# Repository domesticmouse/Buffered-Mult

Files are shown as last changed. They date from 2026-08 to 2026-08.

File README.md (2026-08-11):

# Buffered-Mult

A 3-channel active buffered mult (multiple) circuit designed for Eurorack modular synthesizers. View this in [KiCanvas](https://kicanvas.org/?repo=https%3A%2F%2Fgithub.com%2Fdomesticmouse%2FBuffered-Mult).

## Purpose

In modular synthesis, a **multiple** is used to split a single signal (such as control voltage, gates/triggers, or audio) and route it to multiple destinations simultaneously.

While passive multiples simply wire jacks together in parallel, they cause **voltage droop** when splitting precise voltages like 1V/Octave pitch CV across multiple inputs due to impedance loading. This results in out-of-tune oscillators and pitch tracking errors.

This **buffered mult circuit** solves that problem by using active operational amplifiers configured as unity-gain buffers:

- **1:1 Voltage Precision:** Maintains accurate voltage levels (essential for 1V/Oct pitch CV) across all outputs without signal drop.
- **Impedance Isolation:** High input impedance presents virtually no load to the source signal, while low output impedance cleanly drives downstream module inputs.
- **Channel Isolation:** Prevents attached modules from loading or interfering with each other.

---

## Specifications

### Dimensions
- **Height:** 3U (Eurorack format)
- **Width:** 6HP
- **Faceplate:** Complete mechanical specifications and KiCad panel design are available in [`faceplate/README.md`](faceplate/README.md).

See Exploding Shed's [Eurorack Dimensions Guide](https://www.exploding-shed.com/synth-diy-guides/standards-of-eurorack/eurorack-dimensions/) for sizing a 6hp module.

### Inputs
- **3× 3.5 mm mono input jacks:**
  - Input 2 is normalled to Input 1.
  - Input 3 is normalled to Input 2.
- **Cascading Normalling Routing:**
  - **1 Input patched (Input 1):** Functions as a **1×9** mult (1 input split to 9 outputs).
  - **2 Inputs patched (Inputs 1 & 2):** Functions as **1×3** (Input 1) and **1×6** (Input 2) mults.
  - **3 Inputs patched (Inputs 1, 2 & 3):** Functions as **3 independent 1×3** mults.
- **100 kΩ pulldown resistors** (`R1`–`R3`) on inputs to prevent floating inputs when unpatched.
- **Input ESD & RF Filtering:** 1 kΩ series resistors (`R16`–`R18`) and 100 pF capacitors (`C9`–`C11`) provide high-frequency noise filtering and ESD protection.

### Outputs
- **9× 3.5 mm mono output jacks:** 3 dedicated buffered outputs for each of the 3 input channels.
- **1 kΩ Short-Circuit Protection:** Output series resistors (`R7`–`R15`) protect op-amps during cable insertion/patching shorts while maintaining stability under capacitive cable loads.
- **Bipolar LED Indication:** Opposing-polarity LED pairs (`D1`–`D6`) driven by dedicated active op-amp constant-current stages (`R4`–`R6`) indicate positive (+) and negative (-) voltage states without loading signal lines.

---

## Circuit & Physical Design

- **TL074 Quad Operational Amplifiers:** Configured as high-impedance unity-gain buffers (`U1`, `U2`, `U3`).
- **Active Visual Feedback:** 4th op-amp stage on each TL074 drives bipolar indicator LEDs in a constant-current feedback arrangement.
- **Power Connector:** Standard 2×5-pin IDC header (`J1`) for Eurorack ±12V power connection.
- **Power Filtering & Decoupling:** Bulk 10 µF electrolytic capacitors (`C7`, `C8`) on power entry rails plus 100 nF ceramic decoupling capacitors (`C1`–`C6`) per IC package.
- **Reverse Power Protection:** MBR0520 Schottky diodes (`D7`, `D8`) protect against reverse ribbon cable insertion.
- **Two-Sided Board Layout:** All SMT components on top layer (`F.Cu`); through-hole jacks and LEDs on bottom layer (`B.Cu`) for front panel mounting.

---

## Verification & Fabrication

- **KiCad Electrical Rules Check (ERC):** 0 Errors, 0 Warnings on main board schematic.
- **KiCad Design Rules Check (DRC):** 0 Track / Clearance Errors on main board and faceplate PCB.
- **JLCPCB Automated Assembly Ready:** Complete Gerber ZIP, SMT BOM (`BOM-Buffered-Mult.csv`), and Centroid CPL (`CPL-Buffered-Mult.csv`) generated in [`jlcpcb/production_files/`](jlcpcb/production_files/).
- **Faceplate Fabrication:** Complete KiCad project, panel Gerber files, and drill specs in [`faceplate/`](faceplate/).

## License

BufferedMult is open source and available under the [Apache License 2.0](LICENSE).

## Disclaimer

This is not an official Google product.

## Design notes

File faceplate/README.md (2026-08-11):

# Buffered Mult Faceplate

This directory contains the mechanical specifications and KiCad panel files for the [Buffered Mult control board](../Buffered-Mult.kicad_pro) faceplate.

---

## Technical Specifications

### Panel Outer Dimensions
- **Format:** 3U Eurorack (6 HP width)
- **Height:** 128.50 mm (±0.20 mm tolerance)
- **Width:** 30.00 mm (incorporates standard -0.48 mm clearance against nominal 30.48 mm to prevent rail binding)
- **Thickness:** 1.60 mm (standard PCB FR4) or 2.00 mm aluminum

---

## Mechanical Clearance & Drill Specifications

### 1. Mounting Screw Slots
To allow minor horizontal alignment adjustments when mounting modules:
- **Screw Size:** M3 (3.0 mm)
- **Slot Shape:** Horizontal oval slot
- **Slot Dimensions:** 6.00 mm (width) × 3.20 mm (height)
- **Hole Center Spacing (Vertical):** 122.50 mm (3.00 mm margin from top and bottom panel edges)
- **Hole Center Spacing (Horizontal):** 7.50 mm from left and right edges (22.50 mm offset center-to-center)

### 2. Component Hole Diameters & Tolerances

| Component | Nominal Size | Recommended Drill Dia. | Clearance Margin | Notes |
| :--- | :--- | :--- | :--- | :--- |
| **3.5mm Audio Jacks** | M6 Bushing (6.0 mm) | **6.10 mm – 6.20 mm** | +0.10 mm to +0.20 mm | Accommodates QingPu WQP-PJ398SM / Thonkiconn PJ301M threaded bushings and solder mask build-up. |
| **Indicator LEDs** | 3.0 mm THT LED | **3.20 mm** | +0.20 mm | Ensures smooth fit for 3mm flat-top LEDs or lightpipes without binding. |
| **Mounting Slots** | M3 Screws | **3.20 mm × 6.00 mm** | +0.20 mm | Standard Eurorack oval mounting slot. |

---

## Component Layout & Grid

The panel accommodates **3 identical channel groups** (Channel 1, Channel 2, Channel 3) vertically aligned.

### Per-Channel Grid Layout

| Position | Left Column | Right Column |
| :--- | :--- | :--- |
| **Top Row** | Negative LED Indicator (-) | Positive LED Indicator (+) | 
| **Middle Row** | Channel Input Jack | Output Jack 1 |
| **Bottom Row** | Output Jack 2 | Output Jack 3 |

### Faceplate Component Placements

Faceplate to Control Panel offset = (128.5 - 110)/2 = 9.25mm

Distance between channel groups, 29mm vertical separation.

Measurements from top left of control board.

#### Channel 1

- D1: Negative LED Indicator (-)
  - x: 5.77mm
  - y: 7mm
- D2: Positive LED Indicator (+)
  - x: 11.27mm
  - y: 7mm
- J2: Channel 1 Input Jack
  - x: 8.48mm
  - y: 15mm
- J5: Channel 1 Output Jack 1
  - x: 21.52mm
  - y: 15mm
- J6: Channel 1 Output Jack 2
  - x: 8.48mm
  - y: 25mm
- J7: Channel 1 Output Jack 3
  - x: 21.52mm
  - y: 25mm

#### Channel 2

- D3: Negative LED Indicator (-)
  - x: 5.77mm
  - y: 36mm
- D4: Positive LED Indicator (+)
  - x: 11.27mm
  - y: 36mm
- J3: Channel 2 Input Jack
  - x: 8.48mm
  - y: 44mm
- J8: Channel 2 Output Jack 1
  - x: 21.52mm
  - y: 44mm
- J9: Channel 2 Output Jack 2
  - x: 8.48mm
  - y: 54mm
- J10: Channel 2 Output Jack 3
  - x: 21.52mm
  - y: 54mm

#### Channel 3

- D5: Negative LED Indicator (-)
  - x: 5.77mm
  - y: 65mm
- D6: Positive LED Indicator (+)
  - x: 11.27mm
  - y: 65mm
- J4: Channel 3 Input Jack
  - x: 8.48mm
  - y: 73mm
- J11: Channel 3 Output Jack 1
  - x: 21.52mm
  - y: 73mm
- J12: Channel 3 Output Jack 2
  - x: 8.48mm
  - y: 83mm
- J13: Channel 3 Output Jack 3
  - x: 21.52mm
  - y: 83mm

---

## KiCad Faceplate Design & Fabrication Guidelines

When designing the KiCad PCB faceplate (`faceplate.kicad_pcb`):

1. **Board Outline (Edge.Cuts):** Draw a exact 30.00 mm × 128.50 mm rectangle on `Edge.Cuts` with 0.5 mm fillet radii at the 4 outer corners.
2. **Copper & Mask Clearance:**
   - Keep copper traces and copper fills at least **0.50 mm away** from all board edges.
   - Add exposed unmasked copper rings connected to GND around mounting slots on front/back for ESD chassis grounding.
3. **Silkscreen Graphics:**
   - Use high-contrast silkscreen text (`F.Silkscreen` / `B.Silkscreen`).
   - Clearly label Channels (`CH 1`, `CH 2`, `CH 3`), Inputs (`IN`), Outputs (`1`, `2`, `3`), and LED polarities (`+`, `-`).
4. **Recommended PCB Fabrication Specs:**
   - **Material:** FR4, 1.6 mm thickness
   - **Solder Mask:** Black (Matte Black or Glossy Black)
   - **Silkscreen:** White
   - **Surface Finish:** HASL Lead-Free or ENIG (Electroless Nickel Immersion Gold)

---

## Reference Standards
* Exploding Shed [Eurorack Dimensions Guide](https://www.exploding-shed.com/synth-diy-guides/standards-of-eurorack/eurorack-dimensions/)
* Doepfer [Eurorack Mechanical Specifications](https://doepfer.de/a100_man/a100m_e.htm)

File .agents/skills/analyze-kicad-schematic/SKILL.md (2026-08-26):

---
name: analyze-kicad-schematic
description: >-
  Analyzes KiCad schematic files (.kicad_sch) and generates structured markdown
  reports or targeted query results (BOM, ERC, power rails, signal netlists,
  circuit topologies, unconnected pins). Use this skill when reviewing, auditing,
  or troubleshooting KiCad schematic designs.
---

# KiCad Schematic Analyzer

This skill provides automated analysis of KiCad 7/8/9/10+ schematic (`.kicad_sch`) files using `kicad-cli`. It supports **modular CLI subcommands** so you can query specific aspects of a schematic without polluting the context with monolithic reports, as well as generating full comprehensive Markdown reports.

## Prerequisites

- **uv** (preferred runtime) or **Python 3.6+**
- **KiCad CLI (`kicad-cli`)**: Auto-detected from system `PATH` or standard installation locations:
  - macOS: `/Applications/KiCad/KiCad.app/Contents/MacOS/kicad-cli`, `/Applications/KiCad <version>/...`, Homebrew (`/opt/homebrew/bin/kicad-cli`).
  - Linux: `/usr/bin/kicad-cli`, `/usr/local/bin/kicad-cli`, Snap, Flatpak.
  - Windows: `C:\Program Files\KiCad\<version>\bin\kicad-cli.exe`.

## Tool Script

The analysis script is located at:
- [`scripts/analyze_schematic.py`](./scripts/analyze_schematic.py)

---

## Discovering Commands & Options (`--help`)

Always check `--help` using `uv run --isolated` to inspect available query subcommands or specific subcommand flags:

```bash
# View top-level help and list of subcommands
uv run --isolated .agents/skills/analyze-kicad-schematic/scripts/analyze_schematic.py --help

# View help and filtering options for a specific subcommand
uv run --isolated .agents/skills/analyze-kicad-schematic/scripts/analyze_schematic.py nets --help
uv run --isolated .agents/skills/analyze-kicad-schematic/scripts/analyze_schematic.py bom --help
```

*(Fallback without uv: `python3 .agents/skills/analyze-kicad-schematic/scripts/analyze_schematic.py --help`)*

---

## Targeted Query Subcommands

Instead of running a monolithic report, prefer running the specific subcommand relevant to the question being asked:

| Subcommand | Description | When to use |
| :--- | :--- | :--- |
| `summary` | Design overview, KiCad version, sheet hierarchy, total components/nets | Initial inspection or high-level sanity check |
| `erc` | Runs ERC check (`kicad-cli sch erc`) and reports true electrical errors/warnings | Checking electrical validity, unrouted nets, or conflicts |
| `bom` | Consolidated Bill of Materials table grouped by value, footprint, LCSC/MPN | Part counting, component lookup, sourcing reviews |
| `topologies` (or `circuits`) | Detects RC filters (with $f_c$), op-amp voltage followers, LED feedback drivers | Circuit function understanding, analog verification |
| `power` | Power rails audit (`+12V`, `-12V`, `GND`, etc.) and all connected pins | Power distribution inspection, ground connection audits |
| `nets` | Signal netlist connections with optional `--net` or `--ref` filters | Tracing specific signals or inspecting pins of a component |
| `unconnected` | Unconnected physical pins and explicit no-connect flags | Finding missed connections or unrouted pins |
| `report` (or `all`) | Full comprehensive report combining all sections | Generating a complete archival design review document |

---

## Usage Examples

### 1. Inspect Bill of Materials (BOM)
```bash
uv run --isolated .agents/skills/analyze-kicad-schematic/scripts/analyze_schematic.py bom path/to/design.kicad_sch
```

### 2. Run Electrical Rules Check (ERC)
```bash
uv run --isolated .agents/skills/analyze-kicad-schematic/scripts/analyze_schematic.py erc path/to/design.kicad_sch
```

### 3. Trace a Specific Net or Component Pins
```bash
# Filter signal nets connected to component U1
uv run --isolated .agents/skills/analyze-kicad-schematic/scripts/analyze_schematic.py nets path/to/design.kicad_sch --ref U1

# Filter by net name (e.g. INPUT1)
uv run --isolated .agents/skills/analyze-kicad-schematic/scripts/analyze_schematic.py nets path/to/design.kicad_sch --net INPUT1
```

### 4. Audit Power Rails & Decoupling
```bash
uv run --isolated .agents/skills/analyze-kicad-schematic/scripts/analyze_schematic.py power path/to/design.kicad_sch
```

### 5. Check Unconnected / No-Connect Pins
```bash
uv run --isolated .agents/skills/analyze-kicad-schematic/scripts/analyze_schematic.py unconnected path/to/design.kicad_sch
```

### 6. Detect Circuit Topologies & Filter Cutoffs
```bash
uv run --isolated .agents/skills/analyze-kicad-schematic/scripts/analyze_schematic.py topologies path/to/design.kicad_sch
```

### 7. Generate Full Report to a File
```bash
uv run --isolated .agents/skills/analyze-kicad-schematic/scripts/analyze_schematic.py report path/to/design.kicad_sch -o path/to/report.md
```

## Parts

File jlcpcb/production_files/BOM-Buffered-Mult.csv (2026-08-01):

Comment | Designator | Footprint | LCSC | Quantity
100K | R1,R2,R3 | R_0603_1608Metric_Pad0.98x0.95mm_HandSolder | C25803 | 3
100nF | C1,C2,C3,C4,C5,C6 | C_0603_1608Metric_Pad1.08x0.95mm_HandSolder | C14663 | 6
100pF | C10,C11,C9 | C_0603_1608Metric_Pad1.08x0.95mm_HandSolder | C14858 | 3
10uF/25V | C7,C8 | CP_Elec_5x5.4 | C46550416 | 2
1k | R10,R11,R12,R13,R14,R15,R16,R17,R18,R4,R5,R6,R7,R8,R9 | R_0603_1608Metric_Pad0.98x0.95mm_HandSolder | C21190 | 15
D_Schottky | D7,D8 | D_SMA_Handsoldering | C2480 | 2
TL074 | U1,U2,U3 | SOIC-14_3.9x8.7mm_P1.27mm | C2878713 | 3
OUTPUT3-3 | J13 | Jack_3.5mm_QingPu_WQP-PJ398SM_Vertical_CircularHoles |  | 1
OUTPUT3-2 | J12 | Jack_3.5mm_QingPu_WQP-PJ398SM_Vertical_CircularHoles |  | 1
OUTPUT3-1 | J11 | Jack_3.5mm_QingPu_WQP-PJ398SM_Vertical_CircularHoles |  | 1
OUTPUT2-3 | J10 | Jack_3.5mm_QingPu_WQP-PJ398SM_Vertical_CircularHoles |  | 1
OUTPUT2-2 | J9 | Jack_3.5mm_QingPu_WQP-PJ398SM_Vertical_CircularHoles |  | 1
OUTPUT2-1 | J8 | Jack_3.5mm_QingPu_WQP-PJ398SM_Vertical_CircularHoles |  | 1
OUTPUT1-3 | J7 | Jack_3.5mm_QingPu_WQP-PJ398SM_Vertical_CircularHoles |  | 1
OUTPUT1-2 | J6 | Jack_3.5mm_QingPu_WQP-PJ398SM_Vertical_CircularHoles |  | 1
OUTPUT1-1 | J5 | Jack_3.5mm_QingPu_WQP-PJ398SM_Vertical_CircularHoles |  | 1
INPUT3 | J4 | Jack_3.5mm_QingPu_WQP-PJ398SM_Vertical_CircularHoles |  | 1
INPUT2 | J3 | Jack_3.5mm_QingPu_WQP-PJ398SM_Vertical_CircularHoles |  | 1
INPUT1 | J2 | Jack_3.5mm_QingPu_WQP-PJ398SM_Vertical_CircularHoles |  | 1
Eurorack PWR | J1 | IDC-Header_2x05_P2.54mm_Vertical |  | 1
LED | D6 | LED_D3.0mm_FlatTop |  | 1
LED | D5 | LED_D3.0mm_FlatTop |  | 1
LED | D4 | LED_D3.0mm_FlatTop |  | 1
LED | D3 | LED_D3.0mm_FlatTop |  | 1
LED | D2 | LED_D3.0mm_FlatTop |  | 1
LED | D1 | LED_D3.0mm_FlatTop |  | 1

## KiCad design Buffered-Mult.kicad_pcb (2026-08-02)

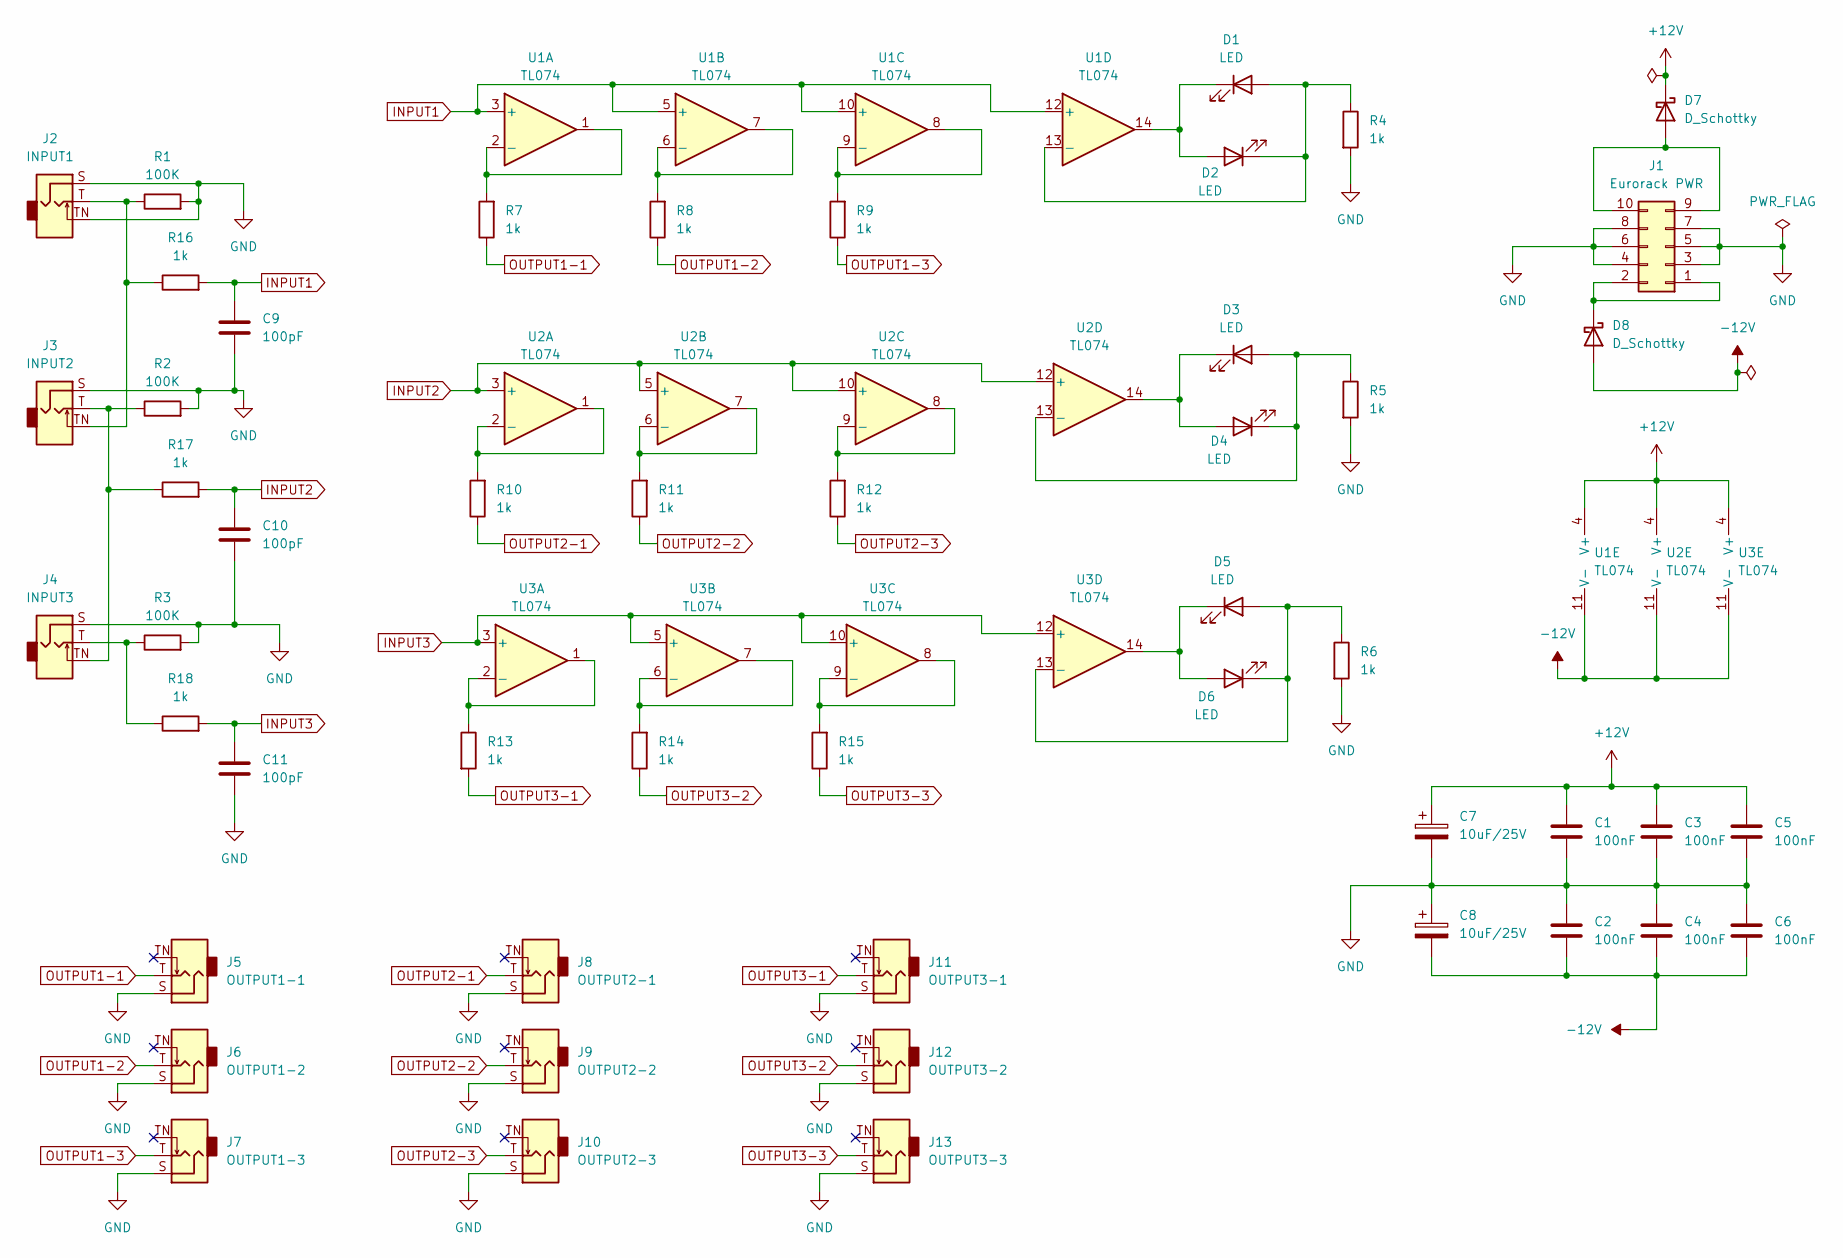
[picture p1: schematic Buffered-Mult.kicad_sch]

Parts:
C1, C2, C3, C4, C5, C6: 100nF; C_0603_1608Metric_Pad1.08x0.95mm_HandSolder; LCSC C14663
C7, C8: 10uF/25V; CP_Elec_5x5.4; LCSC C46550416
C9, C10, C11: 100pF; C_0603_1608Metric_Pad1.08x0.95mm_HandSolder; LCSC C14858
D1, D2, D3, D4, D5, D6: LED; LED_D3.0mm_FlatTop
D7, D8: D_Schottky; D_SMA_Handsoldering; LCSC C2480
J1: Eurorack PWR; IDC-Header_2x05_P2.54mm_Vertical
J2: INPUT1; Jack_3.5mm_QingPu_WQP-PJ398SM_Vertical_CircularHoles
J3: INPUT2; Jack_3.5mm_QingPu_WQP-PJ398SM_Vertical_CircularHoles
J4: INPUT3; Jack_3.5mm_QingPu_WQP-PJ398SM_Vertical_CircularHoles
J5: OUTPUT1-1; Jack_3.5mm_QingPu_WQP-PJ398SM_Vertical_CircularHoles
J6: OUTPUT1-2; Jack_3.5mm_QingPu_WQP-PJ398SM_Vertical_CircularHoles
J7: OUTPUT1-3; Jack_3.5mm_QingPu_WQP-PJ398SM_Vertical_CircularHoles
J8: OUTPUT2-1; Jack_3.5mm_QingPu_WQP-PJ398SM_Vertical_CircularHoles
J9: OUTPUT2-2; Jack_3.5mm_QingPu_WQP-PJ398SM_Vertical_CircularHoles
J10: OUTPUT2-3; Jack_3.5mm_QingPu_WQP-PJ398SM_Vertical_CircularHoles
J11: OUTPUT3-1; Jack_3.5mm_QingPu_WQP-PJ398SM_Vertical_CircularHoles
J12: OUTPUT3-2; Jack_3.5mm_QingPu_WQP-PJ398SM_Vertical_CircularHoles
J13: OUTPUT3-3; Jack_3.5mm_QingPu_WQP-PJ398SM_Vertical_CircularHoles
R1, R2, R3: 100K; R_0603_1608Metric_Pad0.98x0.95mm_HandSolder; LCSC C25803
R4, R5, R6, R7, R8, R9, R10, R11, R12, R13, R14, R15, R16, R17, R18: 1k; R_0603_1608Metric_Pad0.98x0.95mm_HandSolder; LCSC C21190
U1, U2, U3: TL074; SOIC-14_3.9x8.7mm_P1.27mm; LCSC C2878713

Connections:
+12V: C1.1, C3.1, C5.1, C7.1, D7.1 (K), U1.4 (V+), U2.4 (V+), U3.4 (V+)
-12V: C2.2, C4.2, C6.2, C8.2, D8.2 (A), U1.11 (V-), U2.11 (V-), U3.11 (V-)
GND: C1.2, C2.1, C3.2, C4.1, C5.2, C6.1, C7.2, C8.1, C9.2, C10.2, C11.2, J1.3, J1.4, J1.5, J1.6, J1.7, J1.8, J2.S, J2.TN, J3.S, J4.S, J5.S, J6.S, J7.S, J8.S, J9.S, J10.S, J11.S, J12.S, J13.S, R1.2, R2.2, R3.2, R4.2, R5.2, R6.2
INPUT1: C9.1, R16.2, U1.3 (+), U1.5 (+), U1.10 (+), U1.12 (+)
INPUT2: C10.1, R17.2, U2.3 (+), U2.5 (+), U2.10 (+), U2.12 (+)
INPUT3: C11.1, R18.2, U3.3 (+), U3.5 (+), U3.10 (+), U3.12 (+)
unnamed: D1.2 (A), D2.1 (K), R4.1, U1.13 (-)
unnamed: D1.1 (K), D2.2 (A), U1.14
unnamed: D3.2 (A), D4.1 (K), R5.1, U2.13 (-)
unnamed: D3.1 (K), D4.2 (A), U2.14
unnamed: D5.2 (A), D6.1 (K), R6.1, U3.13 (-)
unnamed: D5.1 (K), D6.2 (A), U3.14
unnamed: D7.2 (A), J1.9, J1.10
unnamed: D8.1 (K), J1.1, J1.2
unnamed: J2.T, J3.TN, R1.1, R16.1
unnamed: J3.T, J4.TN, R2.1, R17.1
unnamed: J4.T, R3.1, R18.1
unnamed: R7.2, U1.1, U1.2 (-)
unnamed: R8.2, U1.6 (-), U1.7
unnamed: R9.2, U1.8, U1.9 (-)
unnamed: R10.2, U2.1, U2.2 (-)
unnamed: R11.2, U2.6 (-), U2.7
unnamed: R12.2, U2.8, U2.9 (-)
unnamed: R13.1, U3.1, U3.2 (-)
unnamed: R14.2, U3.6 (-), U3.7
unnamed: R15.2, U3.8, U3.9 (-)
OUTPUT1-1: J5.T, R7.1
OUTPUT1-2: J6.T, R8.1
OUTPUT1-3: J7.T, R9.1
OUTPUT2-1: J8.T, R10.1
OUTPUT2-2: J9.T, R11.1
OUTPUT2-3: J10.T, R12.1
OUTPUT3-1: J11.T, R13.2
OUTPUT3-2: J12.T, R14.1
OUTPUT3-3: J13.T, R15.1

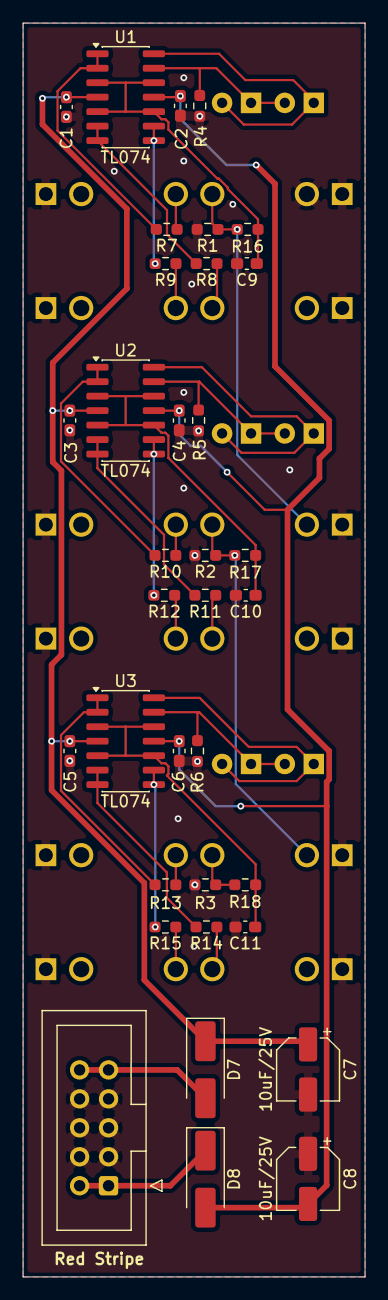
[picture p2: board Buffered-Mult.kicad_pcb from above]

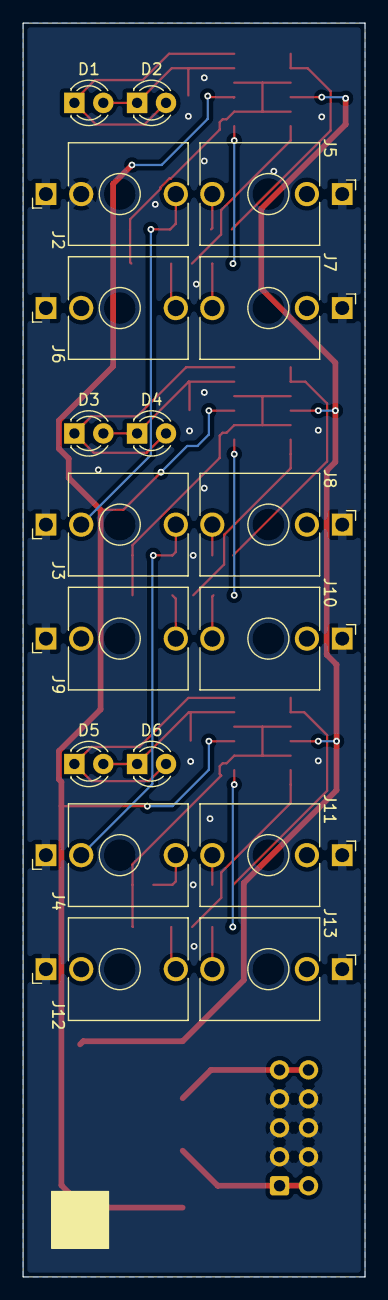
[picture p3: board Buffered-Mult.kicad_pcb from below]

Board: 2 copper layers, 30.0 x 110.0 mm, 53 parts (18 on the bottom side), 35 nets.

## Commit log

2026-07-30 Add kicad project files
    [Buffered-Mult.kicad_pcb, Buffered-Mult.kicad_sch]
2026-07-30 Initial schematic
    [Buffered-Mult.kicad_sch]
2026-07-31 Initial schematic analyzer
2026-07-31 Updated schematic
    [Buffered-Mult.kicad_sch]
2026-07-31 Add LCSC Part numbers
    [Buffered-Mult.kicad_pcb, Buffered-Mult.kicad_sch]
2026-08-01 First draft of PCB
    [Buffered-Mult.kicad_pcb, Buffered-Mult.kicad_sch]
2026-08-01 First cut of production files
    [BOM-Buffered-Mult.csv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]
2026-08-01 Second cut of production files
    [Buffered-Mult-CuBottom.gbr, Buffered-Mult-CuTop.gbr, Buffered-Mult-EdgeCuts.gbr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]
2026-08-01 Data sheets and dimensions
    [Buffered-Mult.kicad_pcb]
2026-08-01 Board layout dimensions
    [Buffered-Mult.kicad_pcb]
2026-08-01 Improve dimensions
    [Buffered-Mult.kicad_pcb]
2026-08-01 Update README with KiCanvas link
    Added a link to view the circuit design in KiCanvas.
2026-08-02 Update layout dimensions
    [Buffered-Mult.kicad_pcb]
2026-08-04 Faceplate WIP
    [Faceplate.kicad_pcb, Faceplate.kicad_sch]
2026-08-07 Adding stuff to faceplate
    [Faceplate.kicad_pcb, Faceplate.kicad_sch]
2026-08-08 Add labels and group separators
    [Faceplate.kicad_pcb]
2026-08-08 Add artwork
    [Faceplate.kicad_pcb]
2026-08-09 Faceplate manufacturing files
    [BOM-Faceplate.csv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]
